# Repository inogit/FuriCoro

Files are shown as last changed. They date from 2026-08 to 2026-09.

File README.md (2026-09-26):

# FuriCoro 🖐️

**Raspberry Pi Pico 2 W で作る、手を振るだけでリモート会議のリアクションを送るガジェット**

手をかざしてスワイプするだけで、Zoom や Teams のリアクション（拍手・いいね・ハートなど）を送れます。
カメラOFFでも使えて、ミュート切り替えや挙手もジェスチャーひとつ。
BLEキーボードとしてPCに繋がるので、ドライバもアプリのインストールも不要です。
なお、開発は生成AIを活用して行なっています。
「Coro」シリーズ第2弾。第1弾は [PomoCoro](https://github.com/inogit/PomoCoro) です。

---

## 📺 デモ

https://github.com/user-attachments/assets/48af5c12-4d48-47eb-b89f-51a5c0a4fe04

---

## ✨ 特徴

- **手をかざすだけ** — センサーの上で手をスワイプ・回転させるとリアクションが飛びます
- **カメラ不要** — 自分の姿を映さずにリアクションできる（Zoom内蔵ジェスチャーはカメラ必須）
- **7種類のリアクション** — Zoom内蔵は2種類のみ。FuriCoroは拍手・いいね・ハート・喜び・祝賀＋ミュート・挙手
- **ミュート・挙手も操作可能** — 手が塞がっていても手をかざすだけ
- **Zoom / Teams 対応、Windows / macOS 切替可能** — 設定モードでOS・アプリを切り替え、電源を切っても記憶
- **すべてジェスチャーで完結** — ボタン不要。誤操作が気になるときはセンサーを伏せて置くだけ

---

## 🕹️ 操作方法

### 通常モード

| ジェスチャー | Zoom | Teams |
|---|---|---|
| 上スワイプ | 拍手 👏 | 拍手 |
| 下スワイプ | いいね 👍 | いいね |
| 左スワイプ | ハート ❤️ | 驚き |
| 右スワイプ | 喜び 😂 | 笑顔 |
| 手を近づける | 祝賀 🎉 | 悲しい |
| 時計回り | ミュート切替 🔇 | ミュート切替 |
| 反時計回り | 挙手切替 ✋ | 挙手切替 |
| 手を引く | 設定モードへ | 設定モードへ |

### 設定モード（手を引くと入る）

| ジェスチャー | 動作 |
|---|---|
| 上/下スワイプ | OS切替（Windows ⇄ macOS）|
| 左/右スワイプ | アプリ切替（Zoom ⇄ Teams）|
| 手を近づける | 確定して通常モードへ戻る |

設定はフラッシュに保存され、電源を切っても記憶されます。

---

## 🛒 必要なパーツ

| パーツ | 購入先 |
|---|---|
| Raspberry Pi Pico 2 W | [スイッチサイエンス](https://www.switch-science.com/products/10053) |
| GROVE - ジェスチャー（PAJ7620U2） | [スイッチサイエンス](https://www.switch-science.com/products/2645) |
| Grove - 0.96インチ OLED（SSD1315） | [スイッチサイエンス](https://www.switch-science.com/products/7002) |
| Raspberry Pi Pico ピンヘッダキット | [スイッチサイエンス](https://www.switch-science.com/products/6991) |
| GROVE - 4ピン-ジャンパオスケーブル | [スイッチサイエンス](https://www.switch-science.com/products/6245) |
| GROVE用 4ピン変換コネクタ（M5STACK-A099） | [スイッチサイエンス](https://www.switch-science.com/products/7093) |
| ブレッドボード | 市販の汎用品でOK |
| microUSBケーブル（データ通信対応） | 手持ちでOK（⚠️ Pico 2 は micro USB）|

詳細は [docs/parts-list.md](docs/parts-list.md) を参照。

---

## 🔌 配線

⚠️ **センサーの電源は必ず 3V3(OUT) から取ってください**（5VだとI2Cバスに5Vが乗り、RP2350を痛める可能性があります）

| 信号 | Pico | → センサー / OLED |
|---|---|---|
| 3.3V | 36番ピン（3V3 OUT） | VCC |
| GND  | 38番ピン | GND |
| SDA  | 6番ピン（GP4） | SDA |
| SCL  | 7番ピン（GP5） | SCL |

I2Cアドレス: センサー `0x73` / OLED `0x3C`

各信号はPicoの1ピンからセンサーとOLEDの2つに分岐します。
詳しい分岐方法は [docs/wiring.md](docs/wiring.md) を参照。

---

## 🛠️ 開発環境のセットアップ

### 1. Arduino IDE に arduino-pico を追加

`ファイル → 基本設定 → 追加のボードマネージャのURL` に以下を追加：

```
https://github.com/earlephilhower/arduino-pico/releases/download/global/package_rp2040_index.json
```

ボードマネージャで **Raspberry Pi Pico/RP2040/RP2350**（作者: Earle F. Philhower, III）をインストール。
⚠️ Arduino公式の Mbed 版ではなく、**Philhower版**を使ってください（BLE HIDが使えます）。

### 2. ボードと設定

- ボード: **Raspberry Pi Pico 2 W**
- ★ **Tools → IP/Bluetooth Stack → IPv4 + Bluetooth**（これを忘れると `KeyboardBLE.h` が見つからずコンパイルエラーになります）

### 3. ライブラリ

ライブラリマネージャで以下をインストール：

- DFRobot_PAJ7620U2
- U8g2（作者: oliver）

---

## 📝 書き込み手順

1. Pico の白いボタン（BOOTSEL）を押しながらUSB接続 → `RPI-RP2` ドライブが現れる
2. スケッチを書き込む
3. **PCのBluetooth設定で「FuriCoro」をペアリング**

---

## 📌 作り方のコツ

- **★ IP/Bluetooth Stack を「IPv4 + Bluetooth」に設定** — これを忘れるとコンパイルできません
- **センサーの電源は 3V3(OUT) から** — 5Vは厳禁
- **書き込み後は再ペアリング** — スケッチを書き込むとPicoのBLE識別情報が変わるため、PC側で「FuriCoro」を一度削除して再ペアリングしてください。OLEDにジェスチャーが表示されるのにZoomが反応しないときは、まずこれを試します。完成後、普段使う分には最初の1回だけでOKです
- **回転ジェスチャー（ミュート・挙手）は人差し指1本で** — 手のひら全体だと回転前の動きがスワイプと誤認識されやすいです
- **ミュートと挙手はグローバル対応** — Zoomの設定で「グローバルショートカットを有効にする」をONにすると、Zoomが背面でも効きます。リアクションはZoomが最前面のときだけ効きます

---

## 🎛️ Zoomショートカットの制約

| 機能 | グローバル | 動作条件 |
|---|:---:|---|
| ミュート・挙手 | ✅ 可 | Zoomが背面でもOK（OLEDに `GLOBAL` 表示）|
| リアクション5種 | ❌ 不可 | Zoomが最前面のときだけ（OLEDに `NEEDS FOCUS` 表示）|

---

## 🖨️ オープンフレームスタンド（3Dプリント）

ブレッドボードの代わりに、1枚のパネルと2本の脚で組む専用スタンドを作りました。
ケースで覆わないオープンフレーム構造で、ドライバー1本で組み立てられ、Picoの使い回しも簡単です。

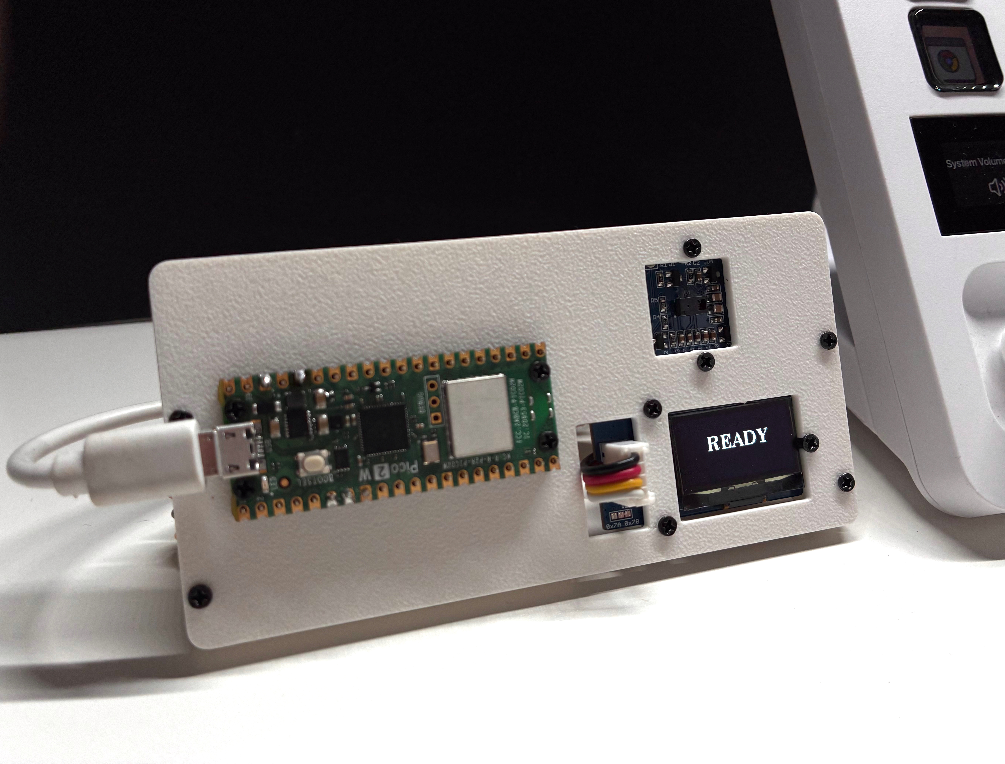
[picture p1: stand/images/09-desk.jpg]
完成


印刷データ・追加パーツ・組み立て手順は [stand/README.md](stand/README.md) を参照。

---

## 📂 ファイル構成

```
FuriCoro/
├── README.md
├── FuriCoro/
│   └── FuriCoro.ino          # メインスケッチ
├── docs/
│   ├── パーツリスト.md
│   └── FuriCoro配線表.md
└── stand/                    # オープンフレームスタンド
    ├── README.md             # 説明・追加パーツ・組み立て手順
    ├── FuriCoro_panel.stl
    ├── FuriCoro_leg_L.stl
    └── FuriCoro_leg_R.stl
```

---

## 📄 ライセンス

[CC BY-NC 4.0](https://creativecommons.org/licenses/by-nc/4.0/deed.ja)

個人利用・改変・再配布は自由です。**商用利用（販売など）はご遠慮ください。**
本作品の利用によって生じたいかなる損害についても、作者は責任を負いません。

---

## 🙏 使用しているライブラリ

| 名称 | 用途 |
|---|---|
| [arduino-pico](https://github.com/earlephilhower/arduino-pico)（KeyboardBLE） | BLE HIDキーボード |
| [DFRobot_PAJ7620U2](https://github.com/DFRobot/DFRobot_PAJ7620U2) | ジェスチャー検出 |
| [U8g2](https://github.com/olikraus/u8g2) | OLED表示 |

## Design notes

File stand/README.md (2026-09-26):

# FuriCoro オープンフレームスタンド 🖐️

**FuriCoro をブレッドボードから卒業させる、3Dプリント製のスタンドです。**

ケースで覆わず、部品をむき出しのまま組む「オープンフレーム」構造にしました。
1枚のパネルにPico・ジェスチャーセンサー・OLEDをネジ止めし、2本の脚で50°に立てます。
配線はすべてコネクタ接続。ドライバー1本で組み立てられ、Picoはいつでも外して別の用途に使い回せます。

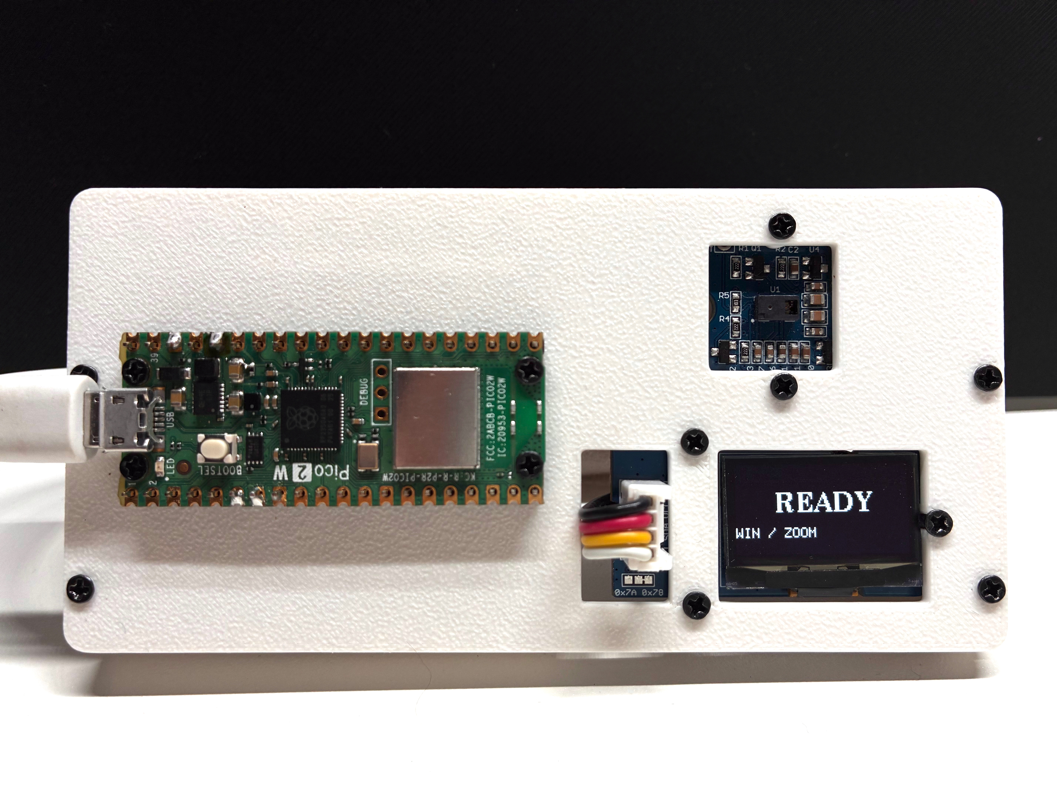
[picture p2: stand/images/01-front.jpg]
完成・正面


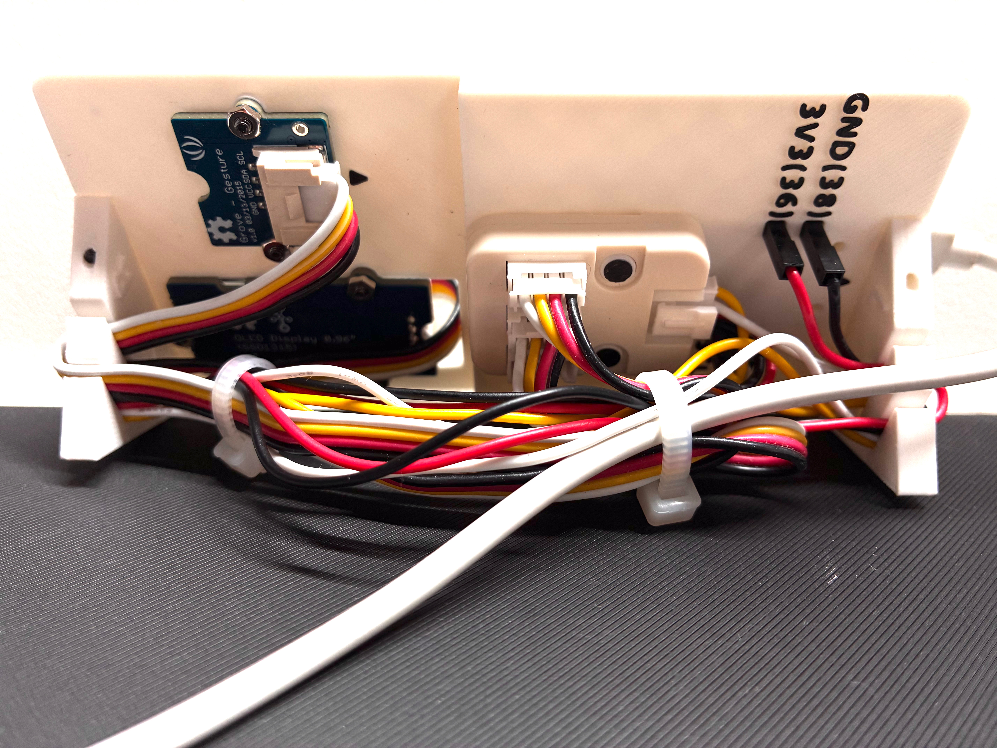
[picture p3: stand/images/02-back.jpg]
完成・裏面


---

## ✨ 設計のポイント

- **ドライバー1本で作れる** — ネジ止めだけ。接着剤も工具も不要
- **パネルの組み立てにハンダ不要** — 配線はGroveケーブルとジャンパーのコネクタ接続だけ
  （Picoにピンヘッダを付けるハンダ付けは必要。**Pico 2 WH** ならそれも不要で完全ハンダレス）
- **Picoの使い回しが簡単** — ネジ4本で外せるので、他のプロジェクトにすぐ転用できる
- **裏面に接続ガイド付き** — ジャンパーの挿し位置（GND / 3V3 / SDA / SCL）と、各コネクタの向き（▲）を凸文字で刻印
- **拡張ハブユニット U006 はネジ不要** — 裏面の突起にレゴブロック感覚で押し込むだけ
- **ケーブル収納スリット** — 脚に2本のスリットがあり、余ったケーブルを巻いてすっきり収納
- **傾斜50°** — Stream Deck + と並べても違和感のない角度

---

## 🖨️ 3Dプリント

| ファイル | 内容 | 数量 |
|---|---|---|
| `FuriCoro_panel.stl` | パネル | 1 |
| `FuriCoro_leg_L.stl` | 左脚（USB側） | 1 |
| `FuriCoro_leg_R.stl` | 右脚（OLED側） | 1 |

**印刷の向き**
- パネル：**表面（Picoを載せる側）を下**にして印刷。裏面の凸文字・突起・スタンドオフが上を向くのでサポート不要
- 脚：**三角形の側面（「L」「R」の刻印が無い方）を下**に寝かせて印刷。高さ5mmで速く、層が板の面と平行になるので強度も出ます。サポート不要

**推奨設定**：PLA、レイヤー0.2mm、インフィル15〜20%、サポートなし

**脚の見分け方**：内側の面に「L」「R」の凸文字があります。右脚は板部が5mm厚くなっています（パネル裏のPico領域の段差を吸収するため）。

---

## 🛒 追加で必要なパーツ

ブレッドボード版の部品に加えて、以下が必要です。

| パーツ | 数量 | 用途 | 購入先 |
|---|---|---|---|
| M5Stack用 拡張ハブユニット [U006] | 1 | I2Cの分岐（1→2） | [スイッチサイエンス](https://www.switch-science.com/products/5696) |
| M5Stack用 GROVEケーブル | 2 | U006 → センサー / OLED | （3本必要。1本はU006に付属）|
| GROVE - 4ピン-ジャンパメスケーブル | 1 | Pico → U006 | [スイッチサイエンス](https://www.switch-science.com/products/1048) |
| M2×8 ネジ | 9 | Pico 4本、センサー 2本、OLED 3本 | — |
| M2×10 ネジ | 4 | 脚の固定 | — |
| M2 ナット | 5 | センサー・OLEDの固定 | — |

ブレッドボード版で使っていたブレッドボード、GROVE-4ピン-ジャンパオスケーブル、GROVE用4ピン変換コネクタは**不要**になります。

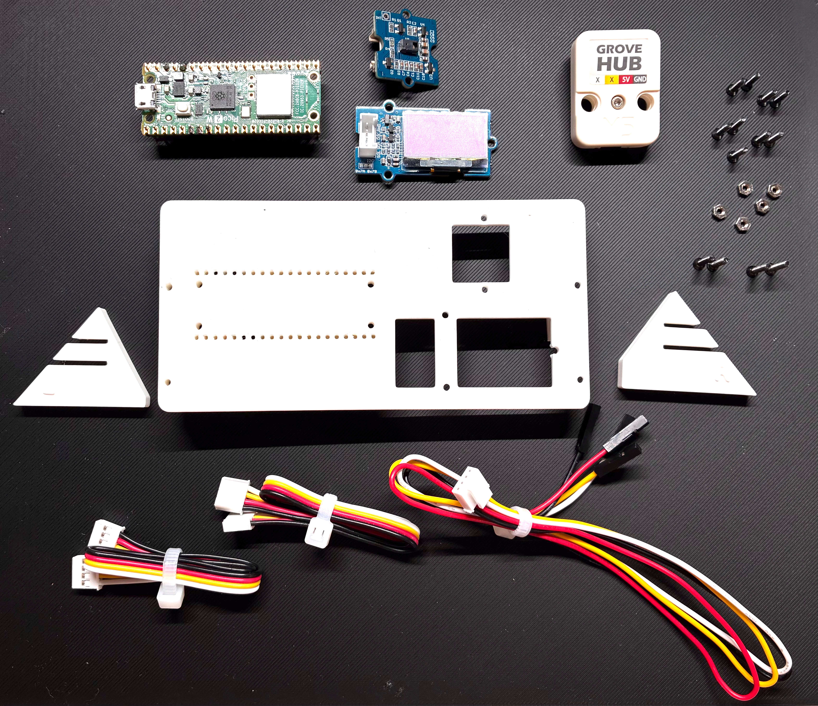
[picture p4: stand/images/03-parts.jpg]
パーツ


---

## 🔧 組み立て手順

### 1. Picoを取り付ける（表から）

Picoはパネルの**表側**に載せます。ピンヘッダをパネルのピン穴に差し込み、四隅をM2×8で固定します。
USBコネクタが左（脚のスリット側）に来る向きです。

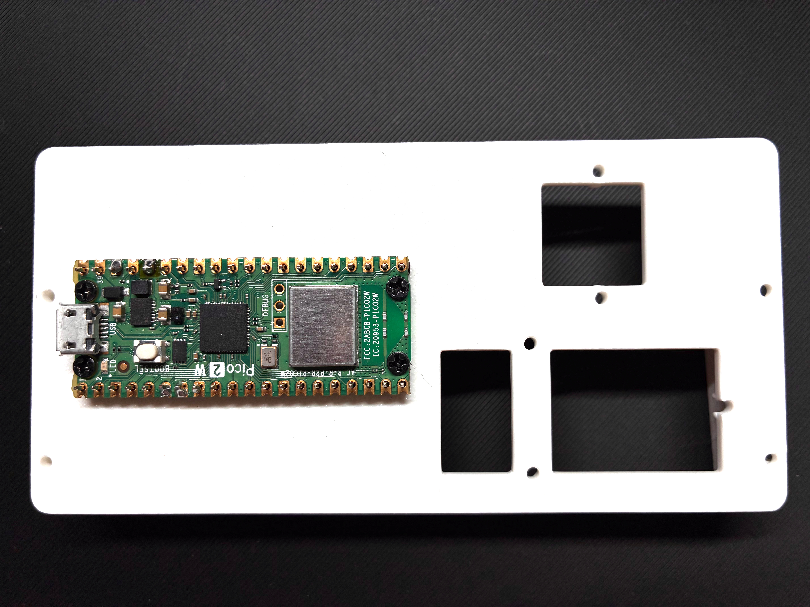
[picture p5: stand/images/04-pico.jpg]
Pico載せ


### 2. センサーとOLEDを取り付ける（裏から）

センサーとOLEDはパネルの**裏側**に付け、窓から表を向かせます。
どちらも**コネクタが裏面の▲マーク側**に来る向きで置いてください。

- **センサー**：上の四角い窓。M2×8を表から通し、裏でナット（2箇所）
- **OLED**：下の窓。M2×8を表から通し、裏でナット（3箇所）

OLEDの窓は2つに分かれています。大きい方がディスプレイ、小さい方がコネクタ用です。

⚠️ **OLEDの短辺側にある1本のネジは締めすぎないでください。** ネジ頭がOLED基板のネジ穴とわずかに干渉するため、強く締めるとディスプレイを破損します。軽く止まる程度で十分です。

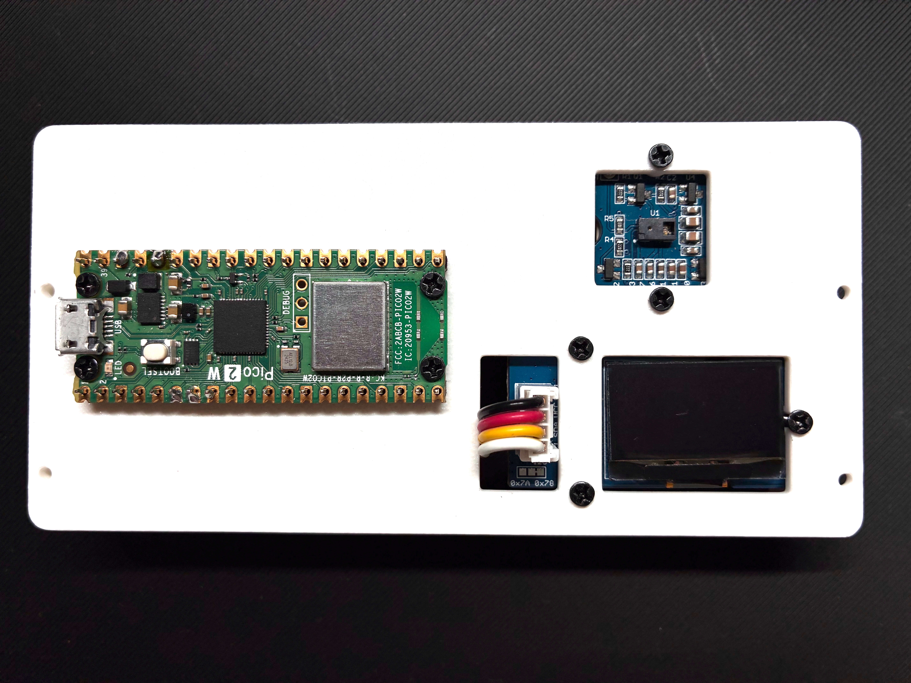
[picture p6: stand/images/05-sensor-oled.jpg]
センサー、OLED載せ


### 3. U006 を取り付ける

裏面のPico領域にある2本の突起に、U006のレゴ穴を合わせて押し込みます。
**入力コネクタがPicoのUSB方向**（画像の一番右▲マーク側）に来る向きです。ネジは不要です。

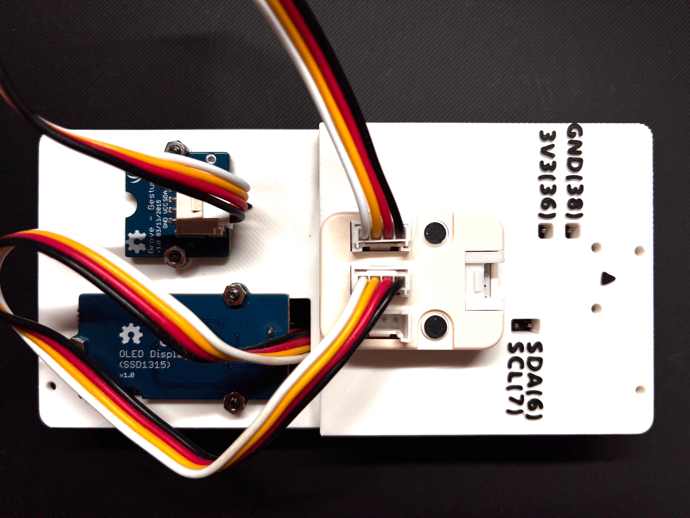
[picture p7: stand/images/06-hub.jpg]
U006載せ


### 4. 配線する

**Pico → U006**
GROVE-4ピン-ジャンパメスケーブルのデュポン側を、裏面のガイドに従って差し込みます。

| 線の色 | 差し込み先 | Pico物理ピン |
|---|---|---|
| 黒 | **GND** | 38 |
| 赤 | **3V3** | 36 |
| 白 | **SDA** | 6 |
| 黄 | **SCL** | 7 |

⚠️ 赤（電源）は必ず **3V3（36番）** です。Groveコネクタ側に「5V」と印字されていても、3.3Vを供給します。

Grove側のコネクタをU006の入力ポートに挿します。

**U006 → センサー / OLED**
GROVEケーブルでU006の残りのポートからセンサーとOLEDへ接続します。U006の3つの出力ポートはどれを使っても同じです。

> （📷 配線を終えた裏面）
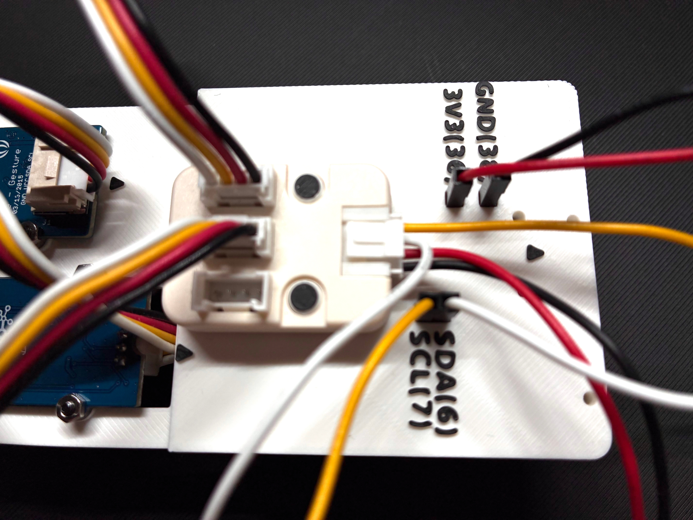
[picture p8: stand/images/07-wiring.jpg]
配線終えた裏面


### 5. 脚を取り付ける

脚の内側に「L」「R」の刻印があります。パネルを表から見て**左にL、右にR**です。
パネルの端に脚を合わせ、表からM2×10を2本ずつ通して締めます。脚側はタッピング穴なのでナットは不要です。

余ったケーブルは脚のスリットに巻き付けて収納します。

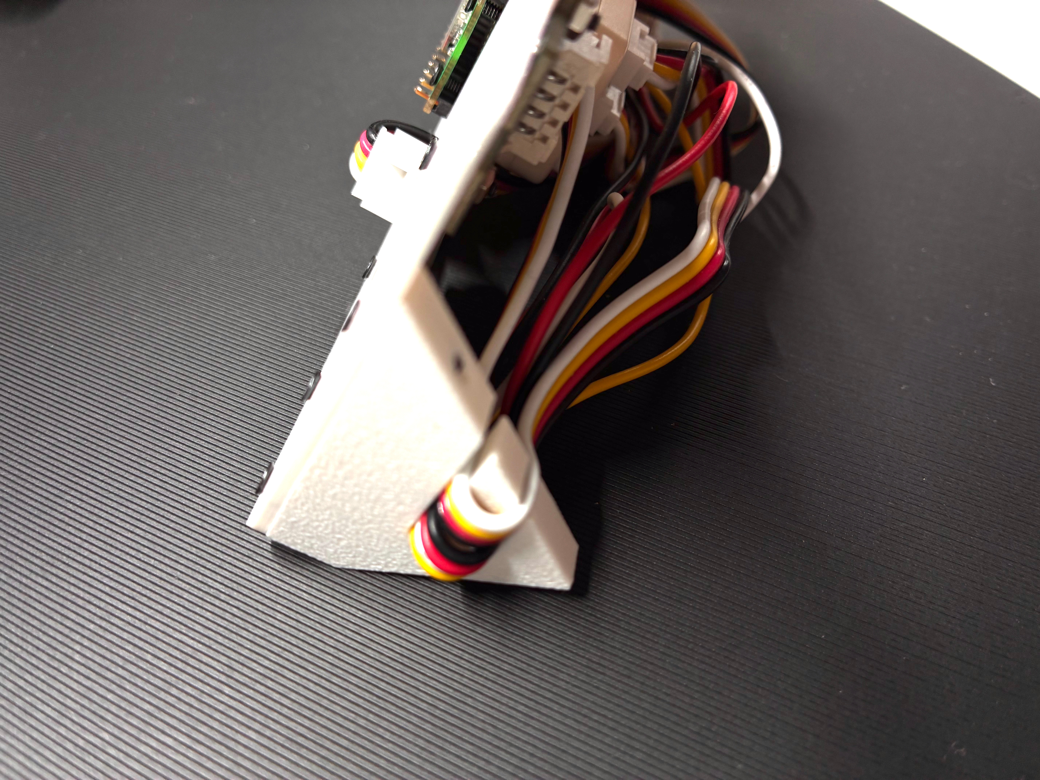
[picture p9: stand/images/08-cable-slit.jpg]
脚のスリット


### 6. 完成

USBケーブルをPicoに挿して電源を入れ、PCとBluetoothでペアリングすれば完成です。
スケッチの変更はありません。ブレッドボード版と同じ `FuriCoro.ino` がそのまま動きます。

完成

---

## 📐 寸法

| | 値 |
|---|---|
| パネル | 117 × 58 × 2mm（Pico領域の裏は7mm） |
| 脚 | 幅5mm、高さ約29mm、奥行き約26mm |
| 傾斜角 | 50° |
| 設置時の高さ | 約46mm |
| 設置時の奥行き | 約37mm |

---

## 📄 ライセンス

[CC BY-NC 4.0](https://creativecommons.org/licenses/by-nc/4.0/deed.ja)（本体と同じ）

個人利用・改変・再配布は自由です。**商用利用（販売など）はご遠慮ください。**
本作品の利用によって生じたいかなる損害についても、作者は責任を負いません。

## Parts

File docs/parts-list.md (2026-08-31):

# FuriCoro パーツリスト

「Coro」シリーズ第2弾。手を振るだけでリモート会議のリアクションを
送るジェスチャーガジェット「FuriCoro」の部品一覧です。

## 必須パーツ（スイッチサイエンスで購入）

| # | 部品 | 数量 | 用途 | 購入先 |
|---|---|:---:|---|---|
| 1 | Raspberry Pi Pico 2 W | 1 | メインマイコン（BLE HID） | https://www.switch-science.com/products/10053 |
| 2 | GROVE - ジェスチャー（PAJ7620U2） | 1 | 手のジェスチャー検出 | https://www.switch-science.com/products/2645 |
| 3 | Grove - 0.96インチ OLEDディスプレイ（SSD1315） | 1 | 認識結果の表示 | https://www.switch-science.com/products/7002 |
| 4 | Raspberry Pi Pico ピンヘッダキット | 1 | Picoにはんだ付け | https://www.switch-science.com/products/6991 |
| 5 | GROVE - 4ピン-ジャンパオスケーブル（5本） | 1 |  センサー/OLEDの配線に2本使用（5本入りなので1つでOK） | https://www.switch-science.com/products/6245 |
| 6 | GROVE用 4ピン変換コネクタ（M5STACK-A099、10個入り） | 1 | ブレッドボード・センサー・OLEDのI2Cコネクタに直接挿せる変換、2個使用（10個入りなので1つでOK） | https://www.switch-science.com/products/7093 |
| 7 | ブレッドボード | 1 | 回路の土台 | （下記※1） |

## 手持ちで用意するもの

| 部品 | 用途 | 備考 |
|---|---|---|
| microUSBケーブル（データ通信対応） | スケッチ書き込み・給電 | ⚠️ Pico 2はmicro USB（USB-Cではない） |
| USB電源（ACアダプタ or モバイルバッテリー） | 動作中の給電 | 手持ちの汎用品でOK |

## 補足

### ※1 ブレッドボードについて
一般的なブレッドボード（400穴程度）で動作します。
市販の汎用品をお使いください。

### オリジナル基板・ケースについて
FuriCoro専用に設計したオリジナルブレッドボードとケースは
別途公開予定です（現在設計中）。

### ⚠️ Pico 2 W と WH について
ピンヘッダ未実装の「Pico 2 W」を使う場合、
ピンヘッダキット（#4）のはんだ付けが必要です。
はんだ付けを避けたい場合は、ピンヘッダ実装済みの
「Pico 2 WH」もありますが、コンテスト対象かは要確認です。

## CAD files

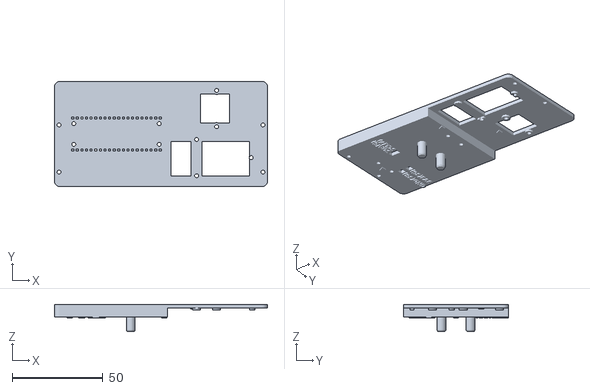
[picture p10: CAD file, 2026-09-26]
stand/FuriCoro_panel.stl
117.3 x 58.0 x 15.0

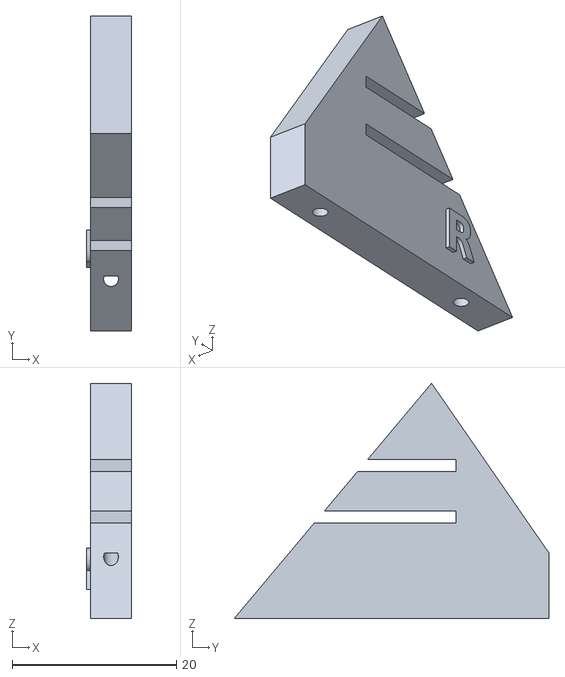
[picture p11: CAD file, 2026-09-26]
stand/FuriCoro_leg_R.stl
5.50 x 38.3 x 28.6

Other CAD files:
stand/FuriCoro_leg_L.stl

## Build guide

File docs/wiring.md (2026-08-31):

# FuriCoro 配線表

Pico のピンと、ブレッドボードの行（a / b / i / j）、
接続先（センサー / OLED）の対応表です。
（実機配線に基づく）

## 基本原理

ブレッドボードは**列（縦）が導通**します。Pico を中央の溝をまたいで挿すと、
Pico の左列ピンは **a-e 側**、右列ピンは **f-j 側** に入ります。

- **SDA / SCL**（GP4/GP5）= Pico 左列 → **a, b 行**（a-e側）
- **3.3V / GND**（物理36/38）= Pico 右列 → **i, j 行**（f-j側）

センサーは Pico と同じ行、OLED は隣の行に挿して分岐します。

---

## 配線対応表（メイン）

| 信号 | Pico物理ピン | GPIO等 | BB列 | Pico | センサー | OLED |
|---|---|---|---|---|---|---|
| SDA  | 6番 | GP4 | 列6  | a 行 | a 行 | b 行 |
| SCL  | 7番 | GP5 | 列7  | a 行 | a 行 | b 行 |
| 3.3V | 36番 | 3V3 | 列5  | i 行 | i 行 | j 行 |
| GND  | 38番 | 38 | 列3  | i 行 | i 行 | j 行 |

---

## 見方

各行（信号）について、同じ列に3つのジャンパーが挿さります。

例：**SDA（列6）**
```
列6
 a行 ← Pico GP4(6番)     ←入力
 a行 ← センサー SDA へ    ←出力1 (Picoと同じa行)
 b行 ← OLED SDA へ        ←出力2 (隣のb行)
```
※ a行とb行は列6の中で縦に導通しているので、
　a行のPico・センサーと、b行のOLEDが全て繋がる

---

## まとめ：センサーとOLEDはどの行か

| 接続先 | 電源系(3.3V/GND) | 信号系(SDA/SCL) |
|---|:---:|:---:|
| **Pico**（入力） | i 行 | a 行 |
| **センサー** | i 行 | a 行 |
| **OLED** | j 行 | b 行 |

**要点：**
- **センサー**は Pico と**同じ行**（電源=i, 信号=a）に挿す
- **OLED**は Pico の**隣の行**（電源=j, 信号=b）に挿す

---

## 各列に挿さるジャンパー（3点）

| 列 | 信号 | i または a 行 | j または b 行 |
|----|---|---|---|
| 列3 | GND  | Pico + センサー | OLED |
| 列5 | 3.3V | Pico + センサー | OLED |
| 列6 | SDA  | Pico + センサー | OLED |
| 列7 | SCL  | Pico + センサー | OLED |

各列で「Pico＋センサー」が i/a 行側、「OLED」が j/b 行側。
アルミがこの列を縦に導通させるので、3点が繋がります。

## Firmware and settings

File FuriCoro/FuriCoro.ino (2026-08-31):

/*
 * FuriCoro  -  Raspberry Pi Pico 2 W で作る
 *              手を振るだけでリモート会議のリアクションを送るガジェット
 *              (Zoom / Teams 対応、Windows / macOS 切替可能)
 * ============================================================
 * 手をかざして動かすと、BLEキーボードとして会議アプリのショートカットを送ります。
 * 
 * PCからは普通のBluetoothキーボードとして見えるため、
 * ドライバもソフトのインストールも不要です。
 *
 * すべての操作を手のジェスチャーで完結させています（ボタン不要）。
 *
 * ------------------------------------------------------------
 * 【必要なハードウェア】
 *   - Raspberry Pi Pico 2 W  (ピンヘッダはんだ付け済み)
 *   - GROVE ジェスチャーセンサ (PAJ7620U2)   I2C 0x73
 *   - GROVE 0.96インチ OLED  (SSD1315/SSD1306) I2C 0x3C
 *
 * 【配線】  ※センサの電源は必ず 3V3(OUT) から取ること
 *   Pico 3V3(OUT) 36番ピン --- ジェスチャ VCC / OLED VCC
 *   Pico GND      38番ピン --- ジェスチャ GND / OLED GND
 *   Pico GP4      6番ピン  --- ジェスチャ SDA / OLED SDA
 *   Pico GP5      7番ピン  --- ジェスチャ SCL / OLED SCL
 *
 * ------------------------------------------------------------
 * 【Arduino IDE の設定】
 *   1. ボード      : Raspberry Pi Pico 2 W
 *   2. ★ IP/Bluetooth Stack : "IPv4 + Bluetooth"
 *
 * 【必要ライブラリ】
 *   - DFRobot_PAJ7620U2
 *   - U8g2  (oliver)
 *
 * ------------------------------------------------------------
 * 【操作方法】
 *   ● 通常モード ────────────────────────
 *     上スワイプ      → 拍手
 *     下スワイプ      → サムズアップ
 *     左スワイプ      → ハート
 *     右スワイプ      → 笑顔
 *     手を近づける    → 祝賀        (Forward)
 *     時計回り        → ミュート切替
 *     反時計回り      → 挙手切替
 *     手を引く        → 設定モードへ (Backward)
 *
 *   ● 設定モード ────────────────────────
 *     上/下スワイプ   → OS切替  (Windows <-> macOS)
 *     左/右スワイプ   → アプリ切替 (Zoom <-> Teams)
 *     手を近づける    → 確定して通常モードへ (Forward)
 *     設定はフラッシュに保存され、電源を切っても記憶されます
 *
 * ------------------------------------------------------------
 * 【使い方】
 *   1. 書き込み後、PCのBluetooth設定で「FuriCoro」をペアリング
 *      ※スケッチを書き込み直したら、PC側でデバイスを削除して
 *        再ペアリングしてください（開発中のみ必要な操作です）
 *   2. Zoom → 設定 → キーボードショートカット で
 *      挙手・ミュートの「グローバルショートカットを有効にする」をON
 *   3. センサの5〜15cm上で手を動かす
 *
 * 【Zoomショートカットの制約】
 *   挙手・ミュート → グローバル対応。Zoomが背面でも効く (OLEDに GLOBAL)
 *   リアクション   → Zoomが最前面のときだけ効く (OLEDに NEEDS FOCUS)
 * ============================================================
 */

#include <Wire.h>
#include <KeyboardBLE.h>
#include <U8g2lib.h>
#include <DFRobot_PAJ7620U2.h>
#include <EEPROM.h>

// ============================================================
//  ★ ユーザー設定エリア
// ============================================================

// BLEデバイス名 (PCのBluetooth一覧に表示される名前)
#define BLE_DEVICE_NAME "FuriCoro"

// I2Cピン
#define PIN_SDA 4
#define PIN_SCL 5

// 起動時のデフォルト (初回のみ。以降はフラッシュ保存値を使用)
#define DEFAULT_OS  0   // 0 = Windows / 1 = macOS
#define DEFAULT_APP 0   // 0 = Zoom    / 1 = Teams

// --- 誤検知対策のパラメータ ---
const unsigned long COOLDOWN_ALL_MS  = 1500;  // 発火後、全ジェスチャー無視
const unsigned long COOLDOWN_SAME_MS = 3000;  // 同一ジェスチャー再受付まで
const unsigned long TOAST_MS         = 2000;  // 送信結果の表示時間

// ============================================================
//  キーコンボ定義
// ============================================================
struct KeyCombo {
  uint8_t mod1;
  uint8_t mod2;
  uint8_t key;
};

// アクションの種類 (OS×アプリで実際のキーが変わる)
enum ActionId {
  ACT_CLAP = 0, ACT_THUMBS, ACT_HEART, ACT_SMILE,
  ACT_PARTY, ACT_HAND, ACT_MUTE,
  ACT_COUNT
};

// ------------------------------------------------------------
//  ショートカットテーブル  [OS][APP][アクション]
//  OS:  0=Windows 1=macOS
//  APP: 0=Zoom    1=Teams
//
//  ⚠️ Zoom(Windows) 以外は実機で未検証の値を含みます。
//     各アプリの設定画面で確認して修正してください。
//     特に Teams のリアクション系は要確認です。
// ------------------------------------------------------------
const KeyCombo SHORTCUTS[2][2][ACT_COUNT] = {
  // ===== Windows =====
  {
    // --- Windows / Zoom ---  (実測済み)
    {
      { KEY_LEFT_ALT, KEY_LEFT_SHIFT, '4' }, // CLAP
      { KEY_LEFT_ALT, KEY_LEFT_SHIFT, '5' }, // THUMBS
      { KEY_LEFT_ALT, KEY_LEFT_SHIFT, '6' }, // HEART
      { KEY_LEFT_ALT, KEY_LEFT_SHIFT, '7' }, // SMILE
      { KEY_LEFT_ALT, KEY_LEFT_SHIFT, '9' }, // PARTY
      { KEY_LEFT_ALT, 0,              'y' }, // HAND  (Alt+Y)
      { KEY_LEFT_ALT, 0,              'a' }, // MUTE  (Alt+A)
    },
    // --- Windows / Teams ---  ⚠️要確認
    {
      { KEY_LEFT_CTRL, KEY_LEFT_SHIFT, '1' }, // CLAP   ?
      { KEY_LEFT_CTRL, KEY_LEFT_SHIFT, '2' }, // THUMBS ?
      { KEY_LEFT_CTRL, KEY_LEFT_SHIFT, '3' }, // HEART  ?
      { KEY_LEFT_CTRL, KEY_LEFT_SHIFT, '4' }, // SMILE  ?
      { KEY_LEFT_CTRL, KEY_LEFT_SHIFT, '5' }, // PARTY  ?
      { KEY_LEFT_CTRL, KEY_LEFT_SHIFT, 'k' }, // HAND  (Ctrl+Shift+K)
      { KEY_LEFT_CTRL, KEY_LEFT_SHIFT, 'm' }, // MUTE  (Ctrl+Shift+M)
    },
  },
  // ===== macOS =====
  {
    // --- macOS / Zoom ---  ⚠️要確認
    {
      { KEY_LEFT_ALT, KEY_LEFT_SHIFT, '4' }, // CLAP   ?
      { KEY_LEFT_ALT, KEY_LEFT_SHIFT, '5' }, // THUMBS ?
      { KEY_LEFT_ALT, KEY_LEFT_SHIFT, '6' }, // HEART  ?
      { KEY_LEFT_ALT, KEY_LEFT_SHIFT, '7' }, // SMILE  ?
      { KEY_LEFT_ALT, KEY_LEFT_SHIFT, '9' }, // PARTY  ?
      { KEY_LEFT_ALT, 0,              'y' }, // HAND   ?
      { KEY_LEFT_GUI, KEY_LEFT_SHIFT, 'a' }, // MUTE  (Cmd+Shift+A)
    },
    // --- macOS / Teams ---  ⚠️要確認
    {
      { KEY_LEFT_GUI, KEY_LEFT_SHIFT, '1' }, // CLAP   ?
      { KEY_LEFT_GUI, KEY_LEFT_SHIFT, '2' }, // THUMBS ?
      { KEY_LEFT_GUI, KEY_LEFT_SHIFT, '3' }, // HEART  ?
      { KEY_LEFT_GUI, KEY_LEFT_SHIFT, '4' }, // SMILE  ?
      { KEY_LEFT_GUI, KEY_LEFT_SHIFT, '5' }, // PARTY  ?
      { KEY_LEFT_GUI, KEY_LEFT_SHIFT, 'k' }, // HAND  (Cmd+Shift+K)
      { KEY_LEFT_GUI, KEY_LEFT_SHIFT, 'm' }, // MUTE  (Cmd+Shift+M)
    },
  },
};

// アクションのメタ情報 (表示名とグローバル可否)
struct ActionMeta {
  const char* label;
  const char* sub;
  bool        isGlobal;   // Zoomが背面でも効くか (挙手・ミュートのみ true)
};
const ActionMeta ACT_META[ACT_COUNT] = {
  { "CLAP",  "applause",    false },
  { "GOOD",  "thumbs up",   false },
  { "HEART", "heart",       false },
  { "SMILE", "smile",       false },
  { "PARTY", "celebrate",   false },
  { "HAND",  "raise hand",  true  },
  { "MUTE",  "mute toggle", true  },
};

// ジェスチャー → アクション の割り当て (通常モード)
typedef DFRobot_PAJ7620U2::eGesture_t Gesture;
struct GestureMap { Gesture g; ActionId act; };
const GestureMap GESTURE_MAP[] = {
  { DFRobot_PAJ7620U2::eGestureUp,            ACT_CLAP   },
  { DFRobot_PAJ7620U2::eGestureDown,          ACT_THUMBS },
  { DFRobot_PAJ7620U2::eGestureLeft,          ACT_HEART  },
  { DFRobot_PAJ7620U2::eGestureRight,         ACT_SMILE  },
  { DFRobot_PAJ7620U2::eGestureForward,       ACT_PARTY  },
  { DFRobot_PAJ7620U2::eGestureClockwise,     ACT_MUTE   },
  { DFRobot_PAJ7620U2::eGestureAntiClockwise, ACT_HAND   },
};
const int GESTURE_MAP_COUNT = sizeof(GESTURE_MAP) / sizeof(GESTURE_MAP[0]);

// ============================================================
//  グローバル
// ============================================================
DFRobot_PAJ7620U2 paj;
U8G2_SSD1306_128X64_NONAME_F_HW_I2C u8g2(U8G2_R0, U8X8_PIN_NONE);

bool  gSensorOK  = false;
int   gOS        = DEFAULT_OS;   // 0=Win 1=Mac
int   gApp       = DEFAULT_APP;  // 0=Zoom 1=Teams
bool  gSetupMode = false;        // 設定モード中か

unsigned long gLastFireMs  = 0;
Gesture       gLastGesture = DFRobot_PAJ7620U2::eGestureNone;
unsigned long gLastSameMs  = 0;

const char*   gToastLabel  = nullptr;
const char*   gToastSub    = nullptr;
bool          gToastGlobal = false;
unsigned long gToastUntil  = 0;

uint16_t      gSendCount   = 0;

// EEPROM(フラッシュ)保存
const int EE_ADDR_MAGIC = 0;
const int EE_ADDR_OS    = 1;
const int EE_ADDR_APP   = 2;
const uint8_t EE_MAGIC  = 0xF3;   // 初期化判定用

// ============================================================
//  設定の保存 / 読み込み
// ============================================================
void saveSettings() {
  EEPROM.write(EE_ADDR_MAGIC, EE_MAGIC);
  EEPROM.write(EE_ADDR_OS,    (uint8_t)gOS);
  EEPROM.write(EE_ADDR_APP,   (uint8_t)gApp);
  EEPROM.commit();
}

void loadSettings() {
  if (EEPROM.read(EE_ADDR_MAGIC) == EE_MAGIC) {
    gOS  = EEPROM.read(EE_ADDR_OS)  & 0x01;
    gApp = EEPROM.read(EE_ADDR_APP) & 0x01;
  } else {
    gOS  = DEFAULT_OS;
    gApp = DEFAULT_APP;
  }
}

const char* osName()  { return gOS  ? "MAC"  : "WIN";  }
const char* appName() { return gApp ? "TEAMS": "ZOOM"; }

// ============================================================
//  キー送信
// ============================================================
void sendCombo(const KeyCombo& kc) {
  if (kc.mod1) KeyboardBLE.press(kc.mod1);
  if (kc.mod2) KeyboardBLE.press(kc.mod2);
  KeyboardBLE.press(kc.key);
  delay(30);
  KeyboardBLE.releaseAll();
}

void fireAction(ActionId act) {
  sendCombo(SHORTCUTS[gOS][gApp][act]);
  gSendCount++;

  const ActionMeta& m = ACT_META[act];
  gToastLabel  = m.label;
  gToastSub    = m.sub;
  gToastGlobal = m.isGlobal;
  gToastUntil  = millis() + TOAST_MS;

  digitalWrite(LED_BUILTIN, HIGH);
  delay(40);
  digitalWrite(LED_BUILTIN, LOW);

  Serial.print("sent: ");
  Serial.print(m.label);
  Serial.print("  [");
  Serial.print(osName()); Serial.print("/"); Serial.print(appName());
  Serial.println("]");
}

// ============================================================
//  OLED 描画
// ============================================================
void drawSetup() {
  u8g2.clearBuffer();

  u8g2.setFont(u8g2_font_6x10_tf);
  u8g2.drawStr(30, 8, "-- SETUP --");
  u8g2.drawHLine(0, 11, 128);

  // OS 行
  u8g2.setFont(u8g2_font_ncenB14_tr);
  char line1[20];
  snprintf(line1, sizeof(line1), "OS:  [%s]", osName());
  u8g2.drawStr(6, 32, line1);

  // APP 行
  char line2[20];
  snprintf(line2, sizeof(line2), "APP: [%s]", appName());
  u8g2.drawStr(6, 50, line2);

  // フッター
  u8g2.setFont(u8g2_font_5x8_tf);
  u8g2.drawStr(2, 62, "U/D:OS  L/R:APP  Fwd:OK");

  u8g2.sendBuffer();
}

void drawNormal() {
  u8g2.clearBuffer();

  // --- 送信直後のトースト ---
  if (gToastLabel && millis() < gToastUntil) {
    u8g2.setFont(u8g2_font_ncenB18_tr);
    int w = u8g2.getStrWidth(gToastLabel);
    u8g2.drawStr((128 - w) / 2, 22, gToastLabel);

    if (gToastSub) {
      u8g2.setFont(u8g2_font_6x10_tf);
      int sw = u8g2.getStrWidth(gToastSub);
      u8g2.drawStr((128 - sw) / 2, 42, gToastSub);

      // グローバル可否マーカー
      if (gToastGlobal) {
        const char* m = "GLOBAL";
        int mw = u8g2.getStrWidth(m);
        int bx = (128 - mw) / 2 - 4;
        u8g2.drawBox(bx, 46, mw + 8, 11);
        u8g2.setDrawColor(0);
        u8g2.drawStr((128 - mw) / 2, 48, m);
        u8g2.setDrawColor(1);
      } else {
        const char* m = "NEEDS FOCUS";
        int mw = u8g2.getStrWidth(m);
        u8g2.drawStr((128 - mw) / 2, 48, m);
      }
    }

    // クールダウンバー
    unsigned long elapsed = millis() - gLastFireMs;
    if (elapsed < COOLDOWN_ALL_MS) {
      int bw = 120 - (int)(120L * elapsed / COOLDOWN_ALL_MS);
      u8g2.drawBox(4, 60, bw, 3);
    }
    u8g2.sendBuffer();
    return;
  }

  // --- 待機画面 ---
  u8g2.setFont(u8g2_font_6x10_tf);
  u8g2.drawStr(0, 8, "FuriCoro");
  u8g2.drawHLine(0, 11, 128);

  u8g2.setFont(u8g2_font_ncenB14_tr);
  if (gSensorOK) u8g2.drawStr(30, 34, "READY");
  else           u8g2.drawStr(12, 34, "NO SENSOR");

  // 現在のモードと送信数
  u8g2.setFont(u8g2_font_6x10_tf);
  char buf[24];
  snprintf(buf, sizeof(buf), "%s / %s", osName(), appName());
  u8g2.drawStr(0, 52, buf);
  snprintf(buf, sizeof(buf), "sent: %u", gSendCount);
  u8g2.drawStr(0, 62, buf);

  u8g2.sendBuffer();
}

void drawScreen() {
  if (gSetupMode) drawSetup();
  else            drawNormal();
}

// ============================================================
//  設定モードのジェスチャー処理
// ============================================================
void handleSetupGesture(Gesture g) {
  switch (g) {
    case DFRobot_PAJ7620U2::eGestureUp:
    case DFRobot_PAJ7620U2::eGestureDown:
      gOS = !gOS;                       // OSトグル
      Serial.print("OS -> "); Serial.println(osName());
      break;
    case DFRobot_PAJ7620U2::eGestureLeft:
    case DFRobot_PAJ7620U2::eGestureRight:
      gApp = !gApp;                     // アプリトグル
      Serial.print("APP -> "); Serial.println(appName());
      break;
    case DFRobot_PAJ7620U2::eGestureForward:
      // 確定して通常モードへ
      saveSettings();
      gSetupMode  = false;
      gToastLabel = "SAVED";
      gToastSub   = nullptr;
      gToastGlobal= false;
      gToastUntil = millis() + 1200;
      Serial.println("settings saved");
      break;
    default:
      break;   // 回転・Backwardは設定モードでは無視
  }
}

// ============================================================
//  通常モードのジェスチャー処理
// ============================================================
ActionId lookupAction(Gesture g, bool* found) {
  for (int i = 0; i < GESTURE_MAP_COUNT; i++) {
    if (GESTURE_MAP[i].g == g) { *found = true; return GESTURE_MAP[i].act; }
  }
  *found = false;
  return ACT_CLAP;
}

void handleNormalGesture(Gesture g) {
  unsigned long now = millis();

  // Backward = 設定モードに入る
  if (g == DFRobot_PAJ7620U2::eGestureBackward) {
    gSetupMode  = true;
    gToastLabel = nullptr;
    Serial.println("enter SETUP mode");
    return;
  }

  // クールダウン
  if (now - gLastFireMs < COOLDOWN_ALL_MS) return;

  bool found = false;
  ActionId act = lookupAction(g, &found);
  if (!found) return;

  if (g == gLastGesture && now - gLastSameMs < COOLDOWN_SAME_MS) return;

  fireAction(act);
  gLastFireMs  = now;
  gLastGesture = g;
  gLastSameMs  = now;
}

// ============================================================
//  setup()
// ============================================================
void setup() {
  Serial.begin(115200);

  pinMode(LED_BUILTIN, OUTPUT);
  digitalWrite(LED_BUILTIN, LOW);

  EEPROM.begin(16);
  loadSettings();

  Wire.setSDA(PIN_SDA);
  Wire.setSCL(PIN_SCL);
  Wire.begin();

  u8g2.begin();
  u8g2.clearBuffer();
  u8g2.setFont(u8g2_font_ncenB14_tr);
  u8g2.drawStr(4, 30, "FuriCoro");
  u8g2.setFont(u8g2_font_6x10_tf);
  u8g2.drawStr(4, 48, "starting...");
  u8g2.sendBuffer();

  for (int i = 0; i < 10; i++) {
    if (paj.begin() == 0) { gSensorOK = true; break; }
    Serial.println("PAJ7620U2 init retry...");
    delay(500);
  }
  if (gSensorOK) {
    paj.setGestureHighRate(true);
    Serial.println("PAJ7620U2 ready");
  } else {
    Serial.println("PAJ7620U2 NOT FOUND - check wiring / 3V3 power");
  }

  KeyboardBLE.begin(BLE_DEVICE_NAME);
  Serial.println("BLE advertising as \"" BLE_DEVICE_NAME "\" - pair from your PC");

  delay(600);
  drawScreen();
}

// ============================================================
//  loop()
// ============================================================
void loop() {
  if (gSensorOK) {
    Gesture g = paj.getGesture();
    if (g != DFRobot_PAJ7620U2::eGestureNone) {
      if (gSetupMode) handleSetupGesture(g);
      else            handleNormalGesture(g);
    }
  }

  drawScreen();
  delay(50);
}

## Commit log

2026-09-26 ドキュメントのファイル名を英数字に変更
2026-09-26 READMEのリンクを修正
2026-09-26 オープンフレームスタンドを追加、ライセンスをCC BY-NC 4.0に変更
2026-09-26 スタンドのSTLを追加
    [FuriCoro_leg_L.stl, FuriCoro_leg_R.stl, FuriCoro_panel.stl]
2026-09-26 スタンドのSTLを追加、ライセンス表記を修正
2026-09-26 組み立て写真を追加
